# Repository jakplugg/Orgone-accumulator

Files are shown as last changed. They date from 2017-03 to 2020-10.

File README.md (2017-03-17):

# Orgone-accumulator
The Neutron sound orgone accumulator code for DIY and Reatail modules.

THe overclock version will give better sound, it has a higher sample calculation and playback rate.
you must edit boards.txt to allow teensy 144mhz overclock.

no reports of burned teensys from overclocking to 144mhz. it barely gets warm with orgone code (no DMA)

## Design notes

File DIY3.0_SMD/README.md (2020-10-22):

# Orgone-accumulator DIY3
PRELIMINARY INFO

Google sheets BOM:
https://docs.google.com/spreadsheets/d/1yWP0SEDUn4MFoWlR4tSw32LnQw3czUZVgWfFrcoWUo0

Sorry, boards and panels are currently out of stock, you can also check michigan synth works.

Build Guide by Mark Thomson:  
https://drive.google.com/open?id=1N__tNIBf6pU2vMjDG5RvQLvu772NAHjN  

**changed from previous through hole DIY orgones:**

* SMD components (easy soic and 0805)
* option for linear or switching regulator with pi filter.
* "PSI POWER" either way power header via rectifier.

**improvements to circuit:**
* strong transient PWM signal from sub output is routed away from
everything else and has its own op-amp.
* changed CV inputs to use single rail RRIO op amps and no longer require the protection diodes
* changed vref. it is powered on when the teensy LED it lit up, so there is no voltage on the teensy inputs while booting.

This version uses the same code as previous DIY and retail orgones.
 recommended is "144mhz overclock" 
 
boards.txt in [arduinofolder]/hardware/teensy/avr 
must be edited to make 144mhz available.(uncomment appropriate line)

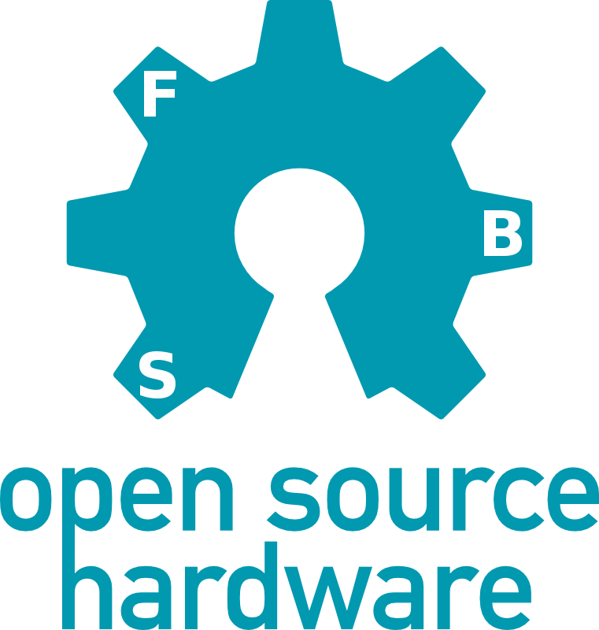
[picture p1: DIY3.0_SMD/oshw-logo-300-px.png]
OSHL


- [ ]mouser BOM
- [*]google BOM
- [*]Build guide
- [*]OSH logo

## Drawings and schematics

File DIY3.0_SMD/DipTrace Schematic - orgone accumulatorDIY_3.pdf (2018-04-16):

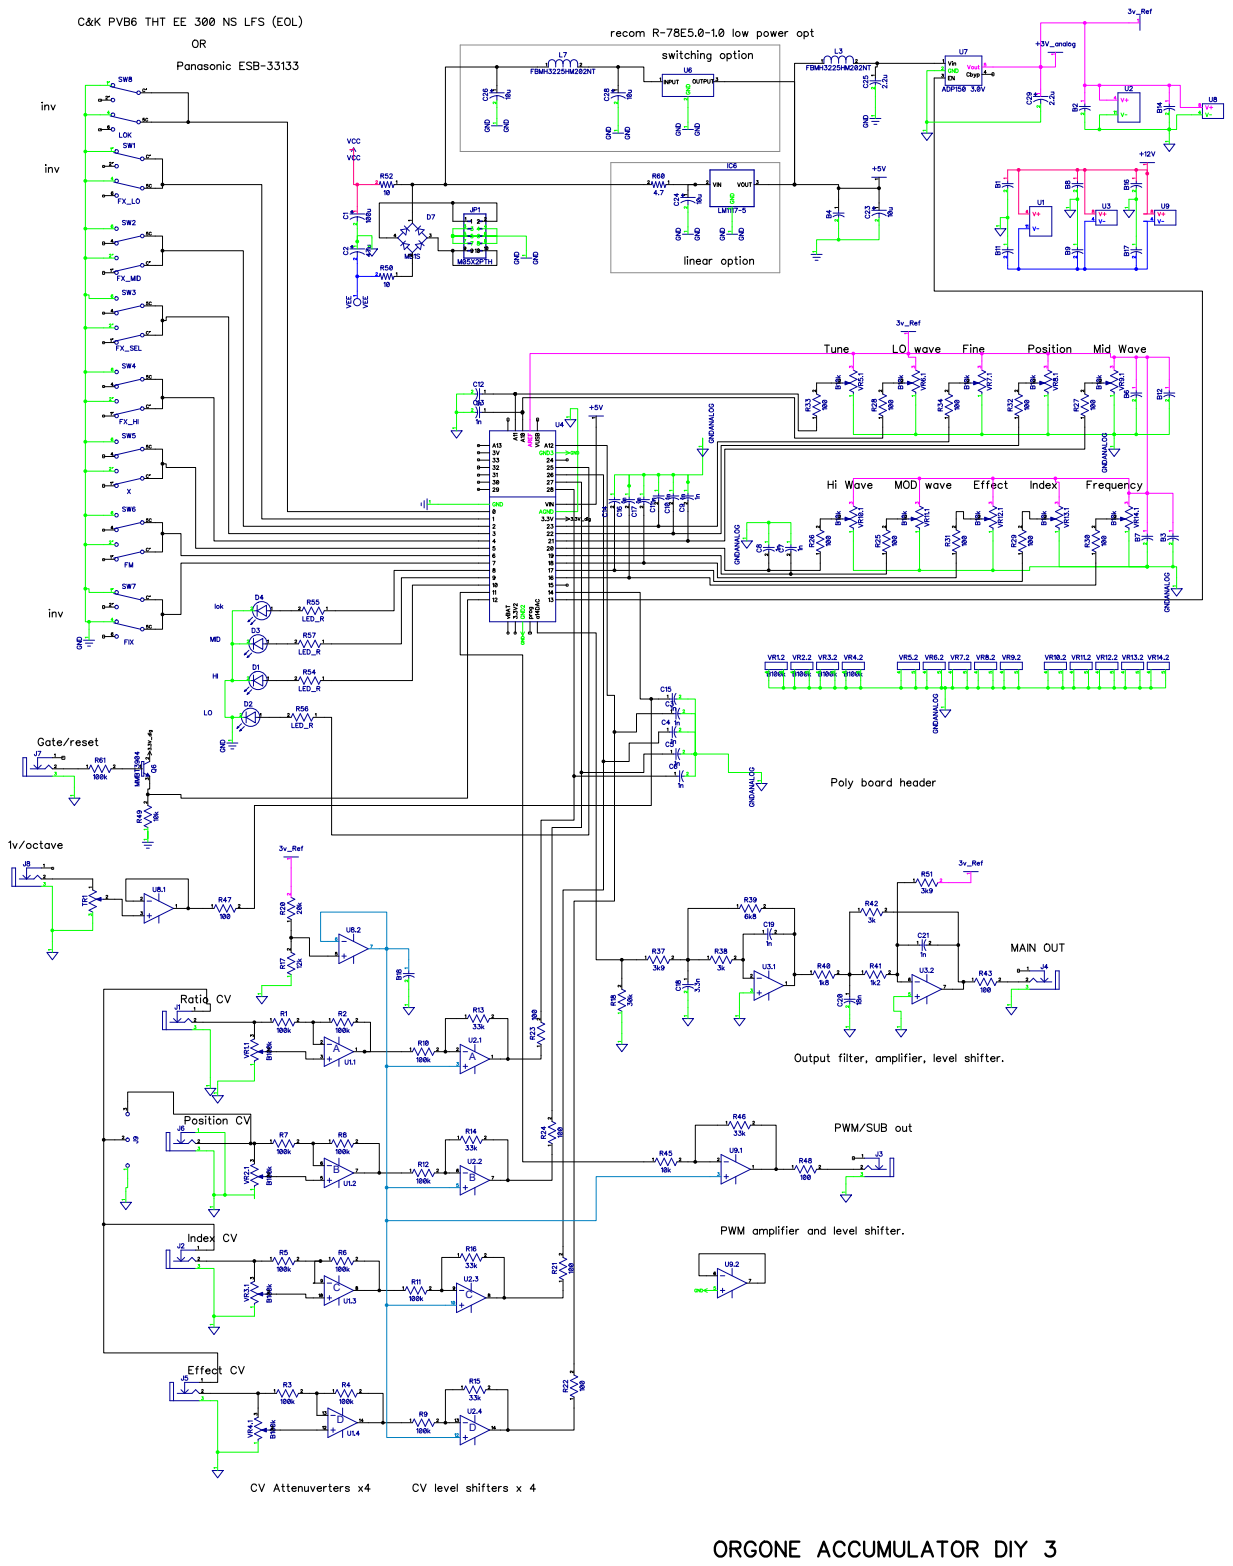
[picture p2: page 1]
ABCD

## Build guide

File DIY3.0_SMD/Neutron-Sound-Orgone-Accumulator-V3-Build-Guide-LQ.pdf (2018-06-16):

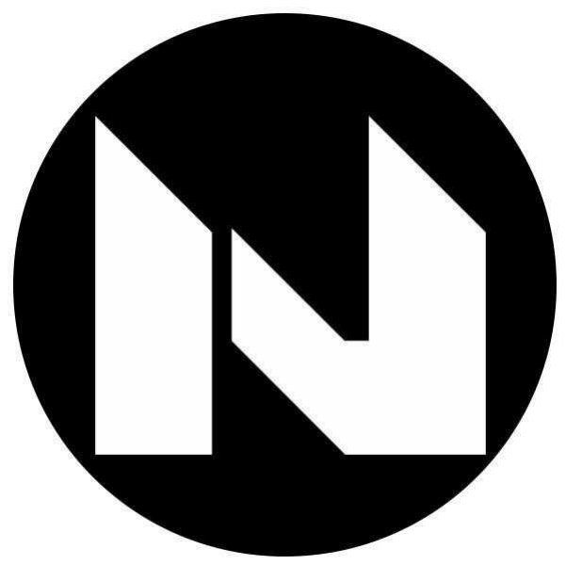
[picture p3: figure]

NEUTRON SOUND

## Build Guide : Orgone Accumulator V3

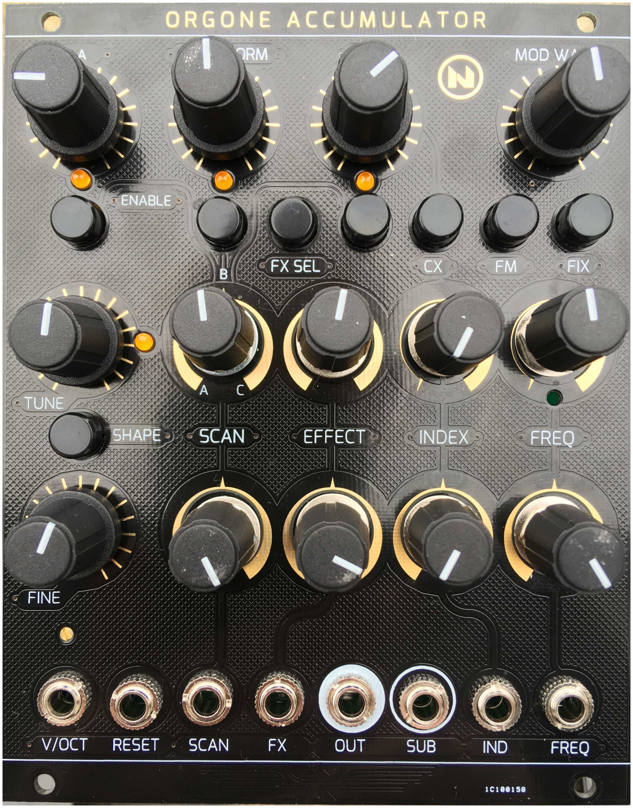
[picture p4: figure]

Build Guide v0.5 (June 2018)

Introduction

Thank you for building a Neutron Sound Orgone Accumulator digital oscillator.

This document will assist you with building the Orgone Accumulator V3, which is an SMD version of the module.

This build is not recommended for beginners to soldering or indeed SMD soldering. If you have no experience of SMD soldering it is recommended that you practice on the widely available SMD practice kits available online.

Bill of Materials (BOM)

You can view the BOM for this project here - Bill of Materials (https://docs.google.com/spreadsheets/d/1yWP0SEDUn4MFoWlR4tSw32LnQw3czUZVgWfFrcoWUo0/edit)

You can use the Mouser Cart here - Mouser Cart (https://www.mouser.com/ProjectManager/ProjectDetail.aspx?AccessID=7d890b8479)

Please note the Mouser Cart does not contain the required Teensy, Jacks, Potentiometers or Knobs, all of which can be sourced from a range of stores depending on your location.

Builders should also note that they have a choice of power supply as indicated in the BOM – it is recommended to use the switching power option which will reduce power consumption, but works out slightly more expensive.

Stock levels vary throughout the year at any component vendor, so you may find some components out of stock if using the Mouser Cart. For most components there are usually a range of suitable alternatives available which can be identifed using the “find similar products” tool. Where there are no suitable alternatives you will usually be able to source an alternative from another vendor.

What equipment do you need to build it?

For soldering SMD projects such as this, having the following equipment is recommended;

- A Soldering Iron with temperature control
- Solder (<0.7mm in diameter)
- SMD Tweezers
- Flux Pen
- Solder Braid
- Hot Air Gun – for reflow and lifting components
- Magnification – some of these components are small!
- Digital Multimeter
- A PC or Mac with Arduino IDE and Teensyduino software installed
Step 1 – Program the Teensy

Make sure you have the latest version of Arduno IDE and Teensyduino downloaded, installed and working on your computer.

Arduino IDE - https://www.arduino.cc/en/Main/Software?
Teensyduino - https://www.pjrc.com/teensy/td_download.html
Go to https://github.com/jakplugg/Orgone-accumulator and download the zip file (the green button on the RHS).

The zip file contains the main firmware. Unzip the file you downloaded from github, and remember the location. Open Arduino IDE, click file/open and navigate to the file you have just downloaded. You should see several tabs in the Arduino IDE if the file was opened properly.

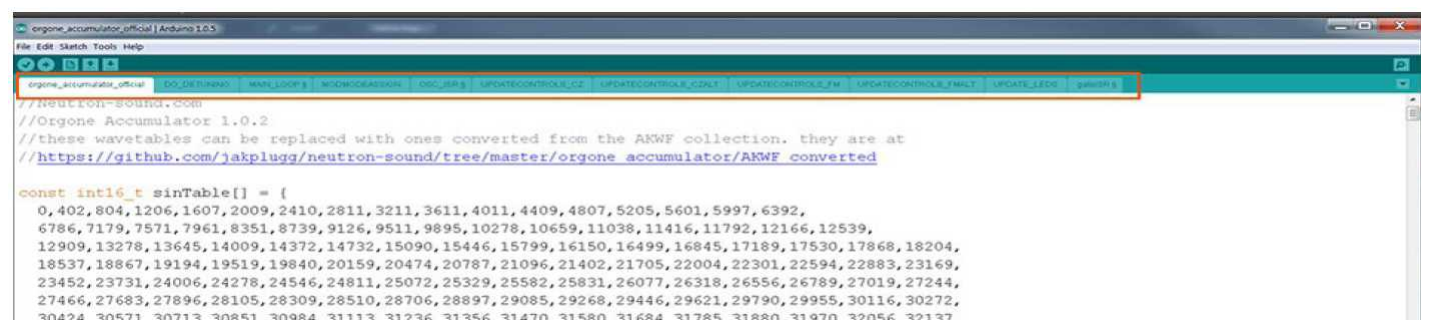
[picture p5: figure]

Now you can go ahead and click the verify button to compile the code, then the upload button to put the firmware on your Teensy.

Overclocking

New versions of the firmware require overclocking the teensy to 144Mhz

This has been widely tested and there have been no reports of overheating or other issues .

To achieve this, you will have to edit the file “boards.txt” it is in:

[where you installed]\arduino\hardware\teensy

in the file you will see a line like this:

#teensy31.menu.speed.144.name=144 MHz (overclock)

all you have to do is remove the “#”
and save.

Next time you open the arduino IDE there will be an additional item in the
Tools>CPU speed for “144MHz (overclock)

Select it before you upload the orgone accumulator sketch to the teensy.

So far I have not found any of the code needs to be edited, the program just executes faster.

At this stage you may wish to cut the power trace on the Teensy.

Cutting this trace still allows the Teensy to be programmed via USB while it is connected to the Modular power,however, the Teensy will no longer work on USB power alone.

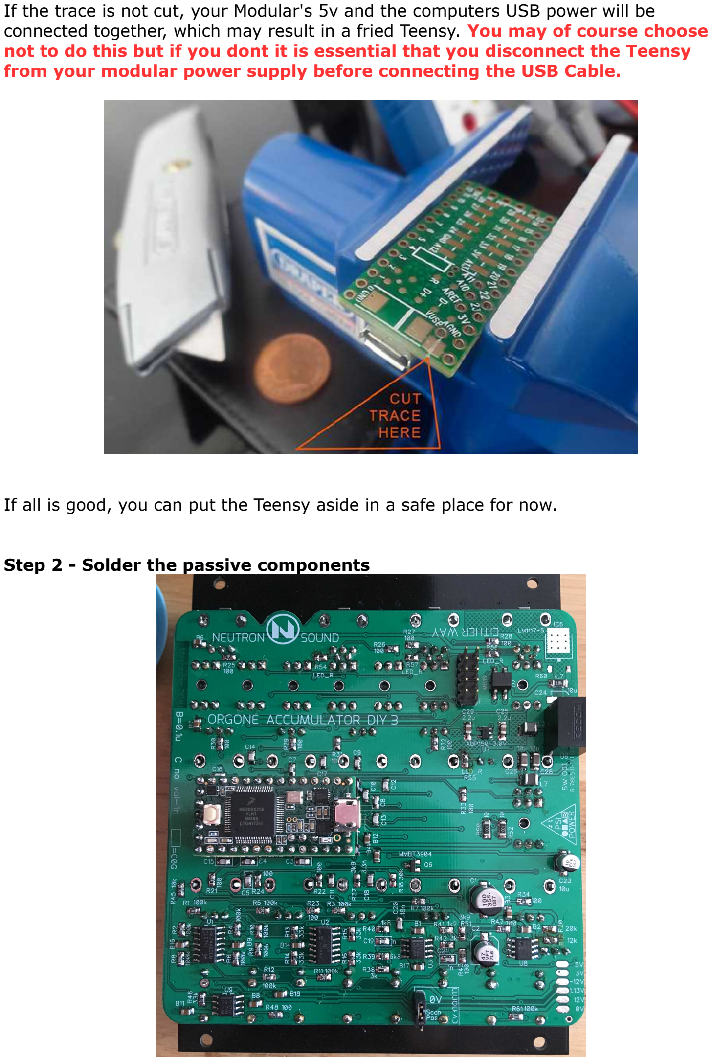
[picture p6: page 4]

If the trace is not cut, your Modular's 5v and the computers USB power will be connected together, which may result in a fried Teensy. You may of course choose not to do this but if you dont it is essential that you disconnect the Teensy from your modular power supply before connecting the USB Cable.

If all is good, you can put the Teensy aside in a safe place for now.

Step 2 - Solder the passive components

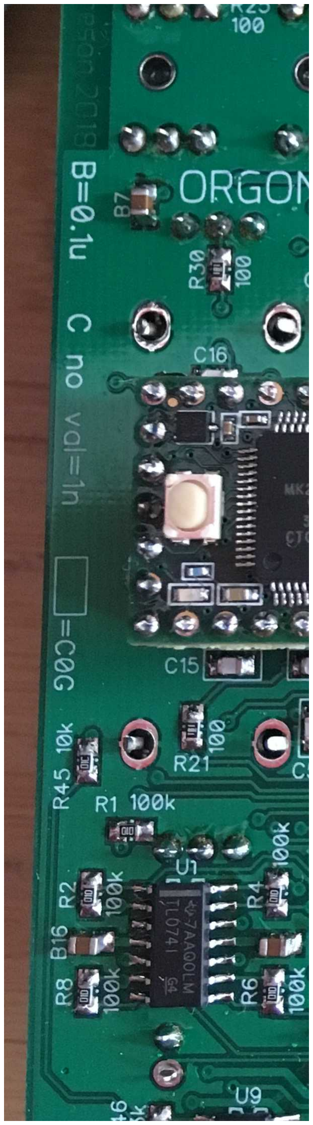
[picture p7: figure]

The Resistors / Capacitors should pose no significant issues if you are familiar with soldering SMD components.

The PCB Silkscreen is clearly marked with reference numbers and values. On the LHS of the PCB there is also a Legend specific to the capacitor values is shown on the silkscreen.

Resistors
13 100k | | R1, R2, R3, R4, R5, R6, R7, R8, R9, R10, R11, R12, R61
5 33k | | R13, R14, R15, R16, R46
1 12k | | R17
1 30k | | R18
1 20k | | R20
17 100R | | R21, R22, R23, R24, R25, R26, R27, R28, R29, R30, R31, R32, R33, R34, R43, R47, R48,
2 3k9 | | R37, R51
2 3k | | R38, R42
1 6k8 | | R39
1 1k8 | | R40
1 1k2 | | R41
2 10k | | R45, R49
2 10R | | R50, R52
4 2.7k | | R54, R55, R56, R57 | You may wish to adjust the value of these resistors to suit your preference in terms of the brightness of the LED
1 | 4.7 R60 | | * R60 used for Linear Power Option only

Ceramic Capacitors

14 100n | B1, B2, B3, B4, B6, B7, B8, B9, B11, B12, B14, B16, B17, B18
13 1n | C3, C4, C5, C6, C9, C10, C11, | 805

| C12, C13, C14, C15, C16, C17
4 1n | C7, C8, C19, C21 | 603
1 3.3n | C18
1 18n | C20
2 2.2u | C25, C29 | 805
2 10u | C26, C28 | * C26 & 28 used for Switching Power Option only
Step 3 - Solder the ICs / MB1S / Transistor / Power etc

There are no significant challenges in soldering these components, but you may find the use of some additional flux will help with soldering and reduce the chances of solder bridges.

You only need small amounts of solder to mount these components, the use of too much increases the chances of solder bridges.

If you encounter any solder bridges or have excessive solder, this can be carefully removed using solder wick and flux.

1 MB1S | | D7
1 LM1117-5 | | IC6 | * IC6 used for Linear Power Option only
1 FBMH3225HM202NT | | L3
1 33uH | | L7 | * L7 used for Switching Power Option only
1 MMBT3904 | | Q6
1 TL074 | | U1
2 TL072ACD | | U3, U9
1 MCP6002 | | U8
1 MCP6004 | | U2
1 Teensy 3.2 | | U4 | Osh Park is cheapest
1 | 7805 Switching Power U6 | | * U6 used for Switching Power Option only
1 ADP150 3.0V | | U7
Step 4– Solder the Electrolytic Caps

Take care to ensure the Electrolytic Caps have the correct orientation, and note that C24 is only required if you choose the Linear Power option.

1 100u | C1
1 47u | C2
2 10u | C23, C24 | * C24 used for Linear Power Option only

Step 5 - Solder the Power Header & Jumper

Place and solder the 2x5 Header for the Power Supply and the 1x3 Header for the Jumper at the bottom of the board. Due to the use of the MB1S Bridge Rectifier the power cable can be connected either way so there is no need for a shrouded header on the module.

Step 6 – Teensy Hardware

This is actually the trickiest part of the build, so we will go into a bit more detail......

Mounting the pins on the teensy:

The Teensy needs to have pins along both long sides, along the short side, a group of three near one edge, and a special set of 14 pins in the middle which use a SMD connector. Lining these all up correctly can be tricky, so proceed as follows.

Instead of the 14 rows you might expect for the two long sides, break off 2 rows of seven from the breakaway pin strip. These will cover half of each long side, nearest the USB connector. This makes getting at the SMD pins easier, while also giving you an alignment point.

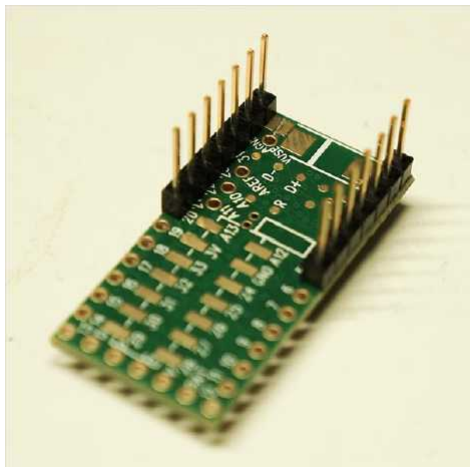
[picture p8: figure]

Get the 7 pin female board header, we are going to use that as an alignment tool, we will call it “alignment tool” for now. Solder in 2 of the 7 pin rows, at the USB end of the Teensy. Just solder one pin for now. Make sure they are vertical and flush to the teensy (you can use “alignment tool”) Now place the alignment tool over the rows you soldered, and also the SMD header,

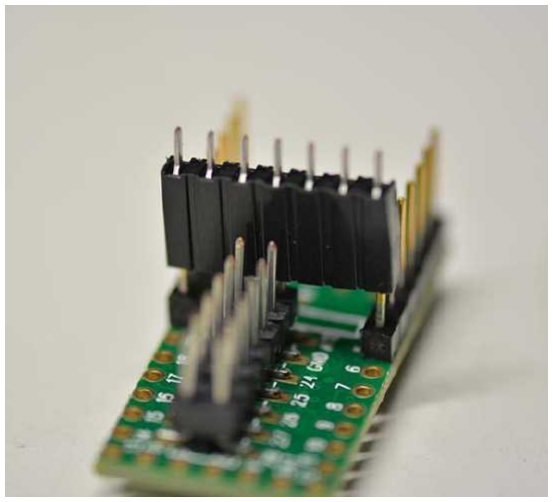
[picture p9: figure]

Solder a couple of the SMD pins, and then remove the “alignment tool” Now you can solder the rest of the SMD pins fairly easily.

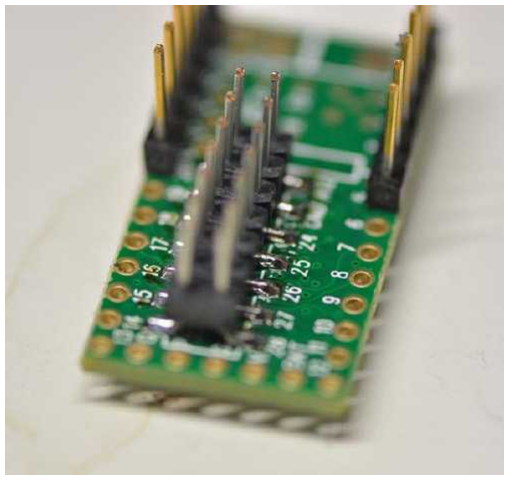
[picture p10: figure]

Now break off 3 pins from the breakaway header and use the alignment tool to hold them in the 3 holes marked AREF A10, and A11 on the Teensy. And solder one pin, to hold them in place.

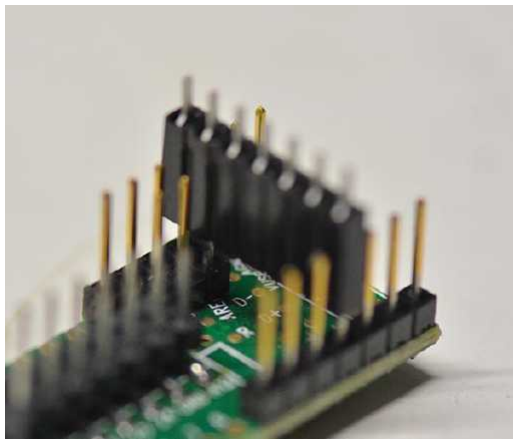
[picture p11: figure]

Now you can break off 2 more strips of 7 pins and place them along the remaining side holes. The alignment tool can be used again You may need to file or sand the ends of the strips you cut, if they interfere with the strips already in place. Just solder 1 pin on each for now.

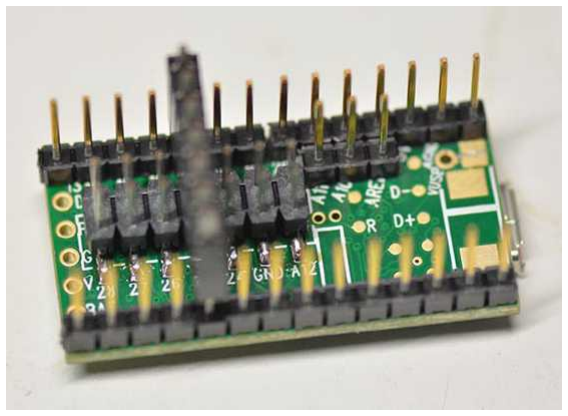
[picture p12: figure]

Now utilize the alignment tool yet again for the remaining 5 pins at the short end of the Teensy. You may now retire the alignment tool and call it a board header again. Again solder only 1 pin.

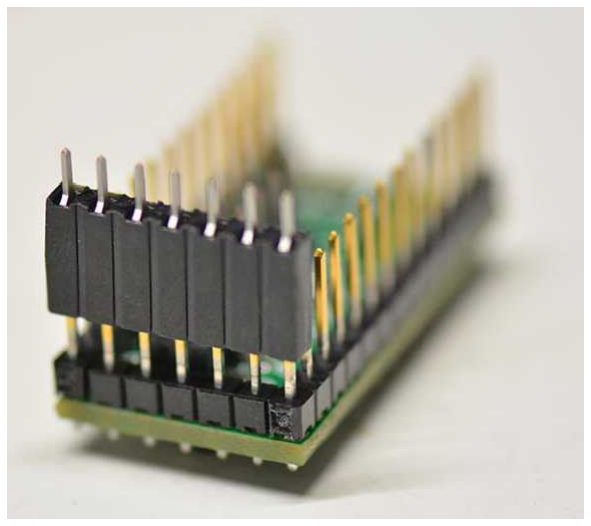
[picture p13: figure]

Mounting the Board Headers

You can put all the headers on their respective pins, to align them all. You will not be able to push them all the way down though; this is fine. Press the 7 pin one on the middle row of the SMD pins first and use that as a guide for how far to press the others. Note that only the “middle” row is used on the SMD header. It is the row that goes down the middle of the Teensy. The other row is just to add stability to the SMD contacts if you have to remove the Teensy.

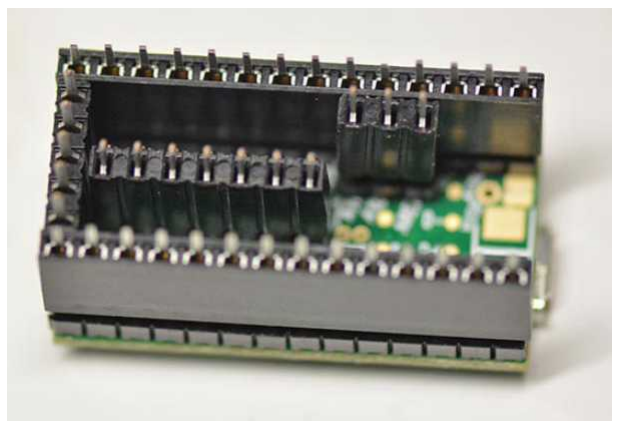
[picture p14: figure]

It can be a bit tricky to get all the header pins in to the Orgone Accumulator board, and you may need to move the pins/header a bit to make if work nicely. This is why you only soldered one pin on each (Idea thanks to hexinverter). Solder all the board headers to the PCB, then all the Teensy pins to the Teensy. Be careful not to get any solder on any Teensy components.

Step 7 – Pots / Jacks / Switches / Trimmer & LEDs

Mount the Pots / Jacks / Switches & Caps / Trimmer and LEDs BUT DO NOT Solder

Pay particular attention to the LED Polarity. Some LEDs have a flat side, which is marked on the board, and LEDs have a longer leg. This is the positive lead.

Ensure you place the B10k & B100k potentiometers in the correct location.

Mount the panel to get a proper fit and ensure everything seated as it should be. The Trimmer should be easily accessible through the panel.

Once everything has been seated correctly and the panel fits correctly, solder the Pots, Switches, LEDs and Jacks.

Step 10 – Clean & Inspect your work and check the voltages

It is good practice to both clean your work and inspect your work under magnification as the build progresses. Prior to powering up for the first time it is worth double-checking for solder bridges etc which may cause damage or malfunction. Pay particular attention to components such as the ADP150, which is the most likely part on this build to have a solder bridge.

The PCB has useful pads on the bottom RHS which allows you to check the various voltages. Whilst the Teensy is removed power the module and check the +- 12v and 5v voltages at these pads using a multimeter. Once you have checked those you can connect the Teensy and check the 3v and 1.13v voltages.

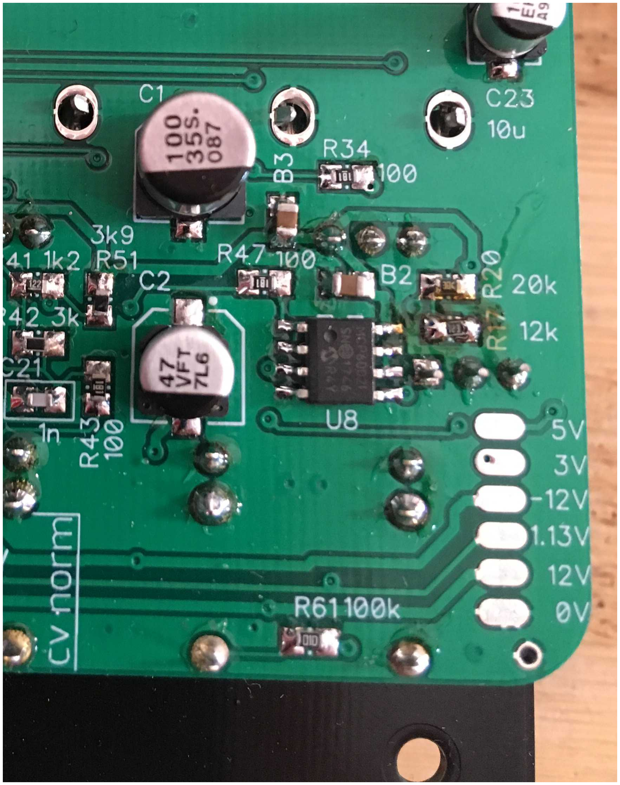
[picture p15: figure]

If there are any issues you may need to check for bridges / shorts, missing components or components with the wrong orientation.

At this stage, particularly after any touch up work, it is worth having a final clean of your completed PCB to remove any flux residue as can be seen in the vicinity of R17 / R20 in the picture above. You can do this using swabs and Isopropyll Alcohol (IPA).

If the voltages are as expected, power off and connect the Teensy. At this stage if you have not done so already, you can mount the button caps of the switches and the knobs of your choice.

The module should be ready to use!

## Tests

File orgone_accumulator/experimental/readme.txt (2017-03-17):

some of these may not work with retail or DIY units, they are just for testing ideas.

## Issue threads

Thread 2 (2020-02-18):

PCB/Panel out of stock

LeonardEyer, 2020-02-18:
Hello! I'd love to build this module of yours. Is it possible to buy a PCB somewhere (EU)?
I could also make them myself if you decide to open source it.

Greetings!

jakplugg, 2020-02-18:
I think i will release the panel files as open source, and just sell
boards. good idea. I should have them up in the next couple of weeks.

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

LeonardEyer, 2020-02-19:
So the PCB will be in stock again soon?

jasonnolan, 2020-02-19:
Synthcube has them in stock in multiple formats. https://synthcube.com/cart/neutron-sound-orgone-accumulator-euro-format

chmanie, 2021-02-22:
Is there any shop in Europe that'd sell me the PCB?

jakplugg, 2021-02-22:
Sorry, I have not heard of any. A synth diy shop can get them from michigan
synth works, but if they order just 1 I expect it will cost more than you
ordering it yourself.

On Mon, Feb 22, 2021 at 8:23 AM Christian Maniewski <
notifications@github.com> wrote:

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

Closed 2021-07-10.

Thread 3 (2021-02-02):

Wrong part number

kidmantis, 2021-02-02:
BOM Problem:  The Teensy SMD header is the wrong Mouser part number.  It comes up with a 1.27" pitch header instead of the 2.54" pitch header required.  Found out the hard way.  :-(

kidmantis, 2021-02-02:
Looks like the simplest solution (at least in N. America) is to pick up the Teensy Header Kit from Spark Fun (https://www.sparkfun.com/products/13925), which is also availible through Mouser (https://www.mouser.ca/ProductDetail/SparkFun/PRT-13925/?qs=wwacUt%252BV97tqN1BEfmG0Sg%3D%3D).  Please post any other sources located to help Jak out.

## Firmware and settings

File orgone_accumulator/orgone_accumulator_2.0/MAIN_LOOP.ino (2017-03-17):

void loop() {
  //histCount ++;
  //if(histCount >= histMax){histCount = 0;}
  
  if (loopReset == 1)goto evilGoto; //these will jump to the same place in the loop after a gateISR happens for better consistancy of retriggered events.

  if (LED_MCD > 0)LED_MCD = LED_MCD - 1;
  if (LED_MCD == 1){WRITE2EEPROM();FXSelArmed[0] = 0;}
  if (QUIET_MCD > 0)QUIET_MCD = QUIET_MCD - 1;
  if (QUIET_MCD == 1){WRITE2EEPROM();FXSelArmed[0] = 0;}

  
  //slow generated signals
  noiseTable2[random(0, 512)] = random(-32767, 32767); //hypnotoad noise (noiseTable2)

    
  if (loopReset == 1)goto evilGoto;
  SWC ++;
  fuh = analogControls[0] >> 6;
  if (SWC > fuh) {
    NT3Rate = (random(-7, 8)) - (noiseTable3[0] / 4198); //LF noise (noiseTable3)
    SWC = 0;
  }

  if (loopReset == 1)goto evilGoto;
  ARC ++;
  if ((ARC == 7 || ARC == 9) && tuneLockOn) ARC ++; //skip reading tuning knobs if tunelock is on.
  if (ARC > 9) {
    ARC = 0;
  }  //cycle through analog controls. skip tuning controls if tunelock is on.
  
  if (loopReset == 1)goto evilGoto;
  //--------------------------------------------------------
  inCVraw = (float)(analogRead(A0)); //main v/oct CV in. only use 13 bits of analog in SEPERATE AINS WITH CODE  
  //--------------------------------------------------------
  if (loopReset == 1)goto evilGoto;
  //______________TUNING OPTIONS  
  dtuner = (float)((((int)(analogControls[9]/227)) * (conf_NoteSize * tuneStep)) + ((int)(analogControls[7] / 28))); //coarse and fine tuning
  tuner = (float)(inCV + dtuner);
  //comment out above line and uncomment following line for analog style non stepped tuning
  //tuner = inCV+(analogControls[9]>>1)+(analogControls[7]>>4);
  //_____________END TUNINGOPTIONS


  if (loopReset == 1)goto evilGoto;
  inputScaler = float(tuner / octaveSize);
  if (loopReset == 1)goto evilGoto;

  //______________________________CONVERSION OPTIONS
  //digitalWriteFast (oSQout,0);//temp testing OC
  //inputVOct = powf(2.0,inputScaler); //uncomment for slightly more accurate v/oct conversion (but it is slower)
  inputVOct = fastpow2(inputScaler); //"real time" exponentiation of CV input! (powf is single precision float power function) comment out if using powf version above
  //digitalWriteFast (oSQout,1);//temp testing OC
  //______________________________END CONVERSION OPTIONS


  //inputVOct = sq(inputScaler);
  if (loopReset == 1)goto evilGoto;
  inputConverter = inputVOct * conf_TuneMult; //<-----------------------------number is MASTER TUNING also affected by ISR speed
  //divide by 2 if you want it play 1 octave lower, 4 for 2 octaves etc.
  //you can also fine tune it to just how you like it by tweaking the number up and down.

  if (loopReset == 1)goto evilGoto;
  //---------------------------------------------------------------------

  READ_POTS();

  //----------------------------------------------------------------------
  if (loopReset == 1)goto evilGoto;
  //running average filter of ratio CV and index CV they are sensetive to noise.
  totalaInRAv = totalaInRAv - readingsaInRAv[indexaInRAv];
  totalaInIAv = totalaInIAv - readingsaInIAv[indexaInRAv];
  totalInCV = totalInCV - readingsaInCV[indexInCV];

  readingsaInRAv[indexaInRAv] = AInRawFilter = (8191 - analogRead(A17)); //adjust numreadingsaInRAv on first page for filtering.
  readingsaInIAv[indexaInRAv] = aInModIndex;
  readingsaInCV[indexInCV] = inCVraw;

  totalaInRAv = totalaInRAv + readingsaInRAv[indexaInRAv];
  totalaInIAv = totalaInIAv + readingsaInIAv[indexaInRAv];
  totalInCV = totalInCV + readingsaInCV[indexInCV];


  indexaInRAv = indexaInRAv + 1;
  if (indexaInRAv >= numreadingsaInRAv) indexaInRAv = 0;
  indexInCV = indexInCV + 1;
  if (indexInCV >= numreadingsCV) indexInCV = 0;

  averageaInRAv = (totalaInRAv / numreadingsaInRAv);
  averageaInIAvCubing = (4095 - (totalaInIAv / numreadingsaInRAv)) / 512.0;
  averageaInIAv = totalaInIAv / numreadingsaInRAv;
  inCV = totalInCV / numreadingsCV;


evilGoto:


  //------------------------------Position CV---------------------
  aInPos = 4095 - ((analogRead(A16))) ;
  //------------------------------------------------------------------
  loopReset = 0;
  envVal = constrain((aInPos + mixPos), 0, 4095); //mix the position knob with the modulation from the CV input (fix for bipolar)

  mixMid = constrain((2047 - abs(envVal - 2047)), 0, 2047); //sets the level of the midpoint wave
  mixHi = constrain((((envVal)) - 2047), 0, 2047); //sets the level of the high wave
  mixLo = constrain((2047 - ((envVal))), 0, 2047); //sets the level of the low wave
  mixEffect = (mixLo * EffectEnOn_A) + (mixMid * EffectEnOn_B) + (mixHi * EffectEnOn_C);


  if (loopReset == 1)goto evilGoto;
  //---------------------------Detune CV----------------
  aInEffectReading = analogRead(A12);
  aInModEffect = ((4095 - aInEffectReading) << 1);
  //--------------------------------------------------

  DODETUNING();

 

  if (loopReset == 1)goto evilGoto;
  //---------------------------Index CV---------------------------------
  aInModIndex = analogRead(A15);
  //----------------------------------------------------------------------

   if (pulsarOn){
   switch (FX){
     
   case 5:
  ASSIGNINCREMENTS_SPECTRUM();//spectral
  break;  
  
  case 7:
  ASSIGNINCREMENTS_DRUM();//drum
  break;   
    
  default:
   ASSIGNINCREMENTS_P();
   }}

   
   else
   switch (FX){
     
  case 5:
  ASSIGNINCREMENTS_SPECTRUM();//spectral
  break;
  
  case 6:
  ASSIGNINCREMENTS_D();//delay
  break;
  
  case 7:
  ASSIGNINCREMENTS_DRUM();//drum
  break;
     
  default:
   ASSIGNINCREMENTS();
   }



  if (loopReset == 1)goto evilGoto;
  UPDATE_POSITION_LEDS();
  
  UPDATE_prog_LEDS();

  if (IsHW2) {
    
    
 if (FXSelArmed[0] == 0){  
    if (FXCycleButton.update()) {
      if (FXCycleButton.fallingEdge()) {
          FXSelArmed[0] = 1; //arm effect selection          
          LED_MCD = LED_MST;
      }
    }   
  }
  else ARMED_FX();

  }

  else {//DIY FX button cycle move
    if (FXCycleButton.update()) {
      if (tuneLockOn) {
        if (FXCycleButton.fallingEdge()) {
          FX = FX - 1;
          if (FX < 0) FX = FX_Count;         
          SELECT_ISRS();
        }
        if (FXSw == 1 && FXCycleButton.risingEdge()) {
          FX = FX - 1;
          if (FX < 0) FX = FX_Count;         
          SELECT_ISRS();
        }
      }


      else {
        if (FXCycleButton.fallingEdge()) {
          FX = FX + 1;
          if (FX > FX_Count) FX = 0;         
          SELECT_ISRS();
        }
        if (FXSw == 1 && FXCycleButton.risingEdge()) {
          FX = FX + 1;
          if (FX > FX_Count) FX = 0;         
          SELECT_ISRS();
        }
      }
    }
  }//end of DIY FX button cycle
  
  // ----------------------------------
  monitorSerialReception();
  if(requestForData) {
    requestForData = false;
    sendBroadcastPacket();
  }
    
//  if(monitorSerialReception) 
//  if(BROADCAST != 0) {  
//    static int pace = 0;
//    if (++pace > 20) {
//      pace = 0;
//      sendBroadcastPacket();
//    }
//  }
  // ----------------------------------



}

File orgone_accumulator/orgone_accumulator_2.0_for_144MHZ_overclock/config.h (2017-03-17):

//neutron orgone accumulator config file. 


#define TUNEMULT 93000 
//#define TUNEMULT 5900000
//this is the base frequency. halving it will lower the entire oscillator by 1 octave 
//real frequency is sent to the broadcast application for tuning

extern const int tuneStep = 1;//this is how many semitones the tuning knob steps in.

#define NOTESIZE 72.0 
// note resolution. lower value will give wider oscillator range, higher will give better resolution
//you will need to recalibrate the v/oct trimmer if you adjust this. decimal is important, even if zero.

#define LED_COMP 1000 //dim the LEDSs higher number = lower brightness. (only for the position LEDs)

//DIY hardware 1.x boards--------------------------------------------------------------------start

#define LED_MODESWITCH_TIME 5000 //time LEDs stay on when effect is switched in main loop cycles, about 2-3000 per second depending on am/fm effects etc.

//LED compensation. adjusts how the LEDs fade across positions

//DIY hardware 1.x boards--------------------------------------------------------------------end
//everyone gets all effects now.

#define FX_SWITCH 1 //dont change for HW2!

//0 = momentary
//1 = toggle

extern const int TUNELOCK_SWITCH = 1;
//0 = tune lock
//1 = pulsar  replaces tune lock with pulsar, reducing FX steps back to 8


#define PWM_SUB 2

//divider to use the PWM as a sub oscillator. DO NOT ENTER ZERO.
//1 = same as main.
//2 = 1 octave down
//4 = 2 octaves etc. 

#define PWM_MINIMUM 4

//128ths of a cycle the thinnest pulse can be. 0 will allow silence to fall.

// Broadcast ---------------------------
extern int BROADCAST;
// Broadcast ---------------------------

//chord intervals each group of 3 numbers is the triplet. dont change the amount of entries!
extern const int chordTable[] = {
  1, 3, 5,
  1, 4, 7,
  1, 3, 7,
  1, 4, 6,
  1, 3, 6,
  1, 5, 9,
  1, 4, 8,
  1, 3, 8,
  1, 4, 9,
};

//#define DECLICK 400 it is dynamic now
//declicking. 4000 = normal operation
//higher number is faster ramp
//do not change the

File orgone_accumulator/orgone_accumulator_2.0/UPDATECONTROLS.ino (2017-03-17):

void UPDATECONTROLS_CZ() {

  if (fixedWave == 1) {
    lo_wavesel_index = analogControls[8] >> 9;
    if ((mixLo > 256) && (lo_wavesel_index != lo_wavesel_indexOld)) {
      declick_ready = 1;
      lo_wavesel_indexOld = lo_wavesel_index;
    }
    waveTableLoLink = CZWTselLo[lo_wavesel_index];


    Mid_wavesel_index = analogControls[5] >> 9;
    if ((mixMid > 256) && (Mid_wavesel_index != Mid_wavesel_indexOld)) {
      declick_ready = 1;
      Mid_wavesel_indexOld = Mid_wavesel_index;
    }
    waveTableMidLink = CZWTselMid[Mid_wavesel_index];

    Hi_wavesel_index = analogControls[4] >> 9;
    if ((mixHi > 256) && (Hi_wavesel_index != Hi_wavesel_indexOld)) {
      declick_ready = 1;
      Hi_wavesel_indexOld = Hi_wavesel_index;
    }
    waveTableHiLink = CZWTselHi[Hi_wavesel_index];
  }

  switch (ARC + 1) {

    case 8:
      //Serial.print(GWTlo1);
      //Serial.print("     ");

      break;

    case 10:


      //outputs the frequency on USB serial. tune lock, FM and X must be off


      break;

    case 3:

      EffectAmountCont = analogControls[2];


      break;

    case 4:

      TUNELOCK_TOGGLE();



      break;

    case 5:




      break;

    case 6: //select hi wave



      if ((analogControls[4] >> 9) == 15) WTShiftHi = 31;
      else WTShiftHi = 23;

      break;

    case 1:
      mixPos = (analogControls[6] >> 1);

      OSC_MODE_TOGGLES();


      break;

    case 7:
      FX_TOGGLES();


      break;

    case 2:
      totalratio = totalratio - readingsratio[controlAveragingIndex];
      readingsratio[controlAveragingIndex] = analogControls[0];
      totalratio = totalratio + readingsratio[controlAveragingIndex];
      controlAveragingIndex = controlAveragingIndex + 1;
      if (controlAveragingIndex >= numreadingsratio) controlAveragingIndex = 0;
      averageratio = totalratio / numreadingsratio;
      break;

    case 9:
      FMIndexCont = (int)(analogControls[1] >> 2);
      FMTable = CZWTselFM[analogControls[3] >> 9];

      break;


  }
}
//--------------------------------------------------------------------CZ-ALT--------------------------------------------------
void UPDATECONTROLS_CZALT() {
  if (fixedWave == 1) {
    lo_wavesel_index = analogControls[8] >> 9;
    if ((mixLo > 256) && (lo_wavesel_index != lo_wavesel_indexOld)) {
      declick_ready = 1;
      lo_wavesel_indexOld = lo_wavesel_index;
    }
    waveTableLoLink = CZAltWTselLo[lo_wavesel_index];

    Mid_wavesel_index = analogControls[5] >> 9;
    if ((mixMid > 256) && (Mid_wavesel_index != Mid_wavesel_indexOld)) {
      declick_ready = 1;
      Mid_wavesel_indexOld = Mid_wavesel_index;
    }
    waveTableMidLink = CZAltWTselMid[Mid_wavesel_index];
  }



  switch (ARC + 1) {

    case 8:

      break;

    case 10:


      break;

    case 3:
      TUNELOCK_TOGGLE();
      EffectAmountCont = analogControls[2];

      break;

    case 4:



      if ((analogControls[5] >> 9) == 15) WTShiftMid = 31;
      else WTShiftMid = 23;


      break;

    case 5:



      break;

    case 6: //no hi wave in alt(x) mode

      FMX_HiOffsetContCub = (analogControls[4] >> 3) - 512;
      FMX_HiOffsetCont = (float)(FMX_HiOffsetContCub * FMX_HiOffsetContCub * FMX_HiOffsetContCub) / 1073741824.0;


    case 1:
      mixPos = analogControls[6] >> 1;

      OSC_MODE_TOGGLES();



      break;

    case 7:
      FX_TOGGLES();


      break;

    case 2:
      totalratio = totalratio - readingsratio[controlAveragingIndex];
      readingsratio[controlAveragingIndex] = analogControls[0];
      totalratio = totalratio + readingsratio[controlAveragingIndex];
      controlAveragingIndex = controlAveragingIndex + 1;
      if (controlAveragingIndex >= numreadingsratio) controlAveragingIndex = 0;
      averageratio = totalratio / numreadingsratio;
      break;

    case 9:
      FMIndexCont = (int)(analogControls[1] >> 2);

      FMTable = CZAltWTselFM[analogControls[3] >> 9];
      FMTableAMX = CZAltWTselFMAMX[analogControls[3] >> 9]; //am mod on hi position

      if ((analogControls[3] >> 9) == 15) WTShiftFM = 31;
      else WTShiftFM = 23;


      break;


  }
}


//----------------------------------------------------------------FM--------------------------------------------------------
void UPDATECONTROLS_FM() {
  if (fixedWave == 1) {
    lo_wavesel_index = analogControls[8] >> 9;
    if ((mixLo > 256) && (lo_wavesel_index != lo_wavesel_indexOld)) {
      declick_ready = 1;
      lo_wavesel_indexOld = lo_wavesel_index;
    }
    waveTableLoLink = FMWTselLo[lo_wavesel_index];

    Mid_wavesel_index = analogControls[5] >> 9;
    if ((mixMid > 256) && (Mid_wavesel_index != Mid_wavesel_indexOld)) {
      declick_ready = 1;
      Mid_wavesel_indexOld = Mid_wavesel_index;

    }
    waveTableMidLink = FMWTselMid[Mid_wavesel_index];

    Hi_wavesel_index = analogControls[4] >> 9;
    if ((mixHi > 256) && (Hi_wavesel_index != Hi_wavesel_indexOld)) {
      declick_ready = 1;
      Hi_wavesel_indexOld = Hi_wavesel_index;
    }
    waveTableHiLink = FMWTselHi[Hi_wavesel_index];
  }


  switch (ARC + 1) {
    case 8: //8 and 10 are skipped when tune lock is on, do not use.
      break;
    case 10:
      break;

    case 3:
      TUNELOCK_TOGGLE();
      EffectAmountCont = analogControls[2];

      break;

    case 4: //mid wave

      break;

    case 5:  //lo wave

      break;

    case 6: //select hi wave


      if ((analogControls[4] >> 9) == 15) WTShiftHi = 31;
      else WTShiftHi = 23;

      break;

    case 1:
      mixPos = (analogControls[6] >> 1);

      OSC_MODE_TOGGLES();

      break;

    case 7:

      FX_TOGGLES();

      break;

    case 2:
      totalratio = totalratio - readingsratio[controlAveragingIndex];
      readingsratio[controlAveragingIndex] = analogControls[0]; //fm ratio control smoothing in FM
      totalratio = totalratio + readingsratio[controlAveragingIndex];
      controlAveragingIndex = controlAveragingIndex + 1;
      if (controlAveragingIndex >= numreadingsratio) controlAveragingIndex = 0;
      averageratio = totalratio / numreadingsratio;
      break;

    case 9:
      FMIndexCont = (int)(analogControls[1] >> 2);

      FMTable = FMWTselFM[analogControls[3] >> 9];
      if ((analogControls[3] >> 9) == 15) WTShiftFM = 31;
      else WTShiftFM = 23;


      break;


  }
}
//--------------------------------------------------------------------------FMALT--------------------------------------------------------------
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

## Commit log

2017-11-28 case change
    changed case of "config" for unix based OS
2018-04-16 psi power
    psi power
2018-04-18 google sheets bom
    someone set us up the BOM
2018-06-17 Update README.md
    wrong link for BOM
2020-02-18 Uploaded PCB Panel, it is now open source.
    [orgone_3_PCBPANEL.DRL, orgone_3_PCBPANEL.GBL, orgone_3_PCBPANEL.GBO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]
